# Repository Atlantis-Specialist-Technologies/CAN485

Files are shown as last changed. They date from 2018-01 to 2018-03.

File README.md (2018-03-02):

# CAN485
Repository for the Sparkfun AST-CAN485 Development Board

Sparkfun AST CAN485

[*Sparkfun AST CAN485 Development Board*](https://www.sparkfun.com/products/14483 "CAN485 on Sparkfun")

# Repository Contents
Repository for the CAN485 Board

* **/Libraries** - Libraries
* **/Examples** - Example code
* **/Documentation** - Documentation
* **/Firmware** - Arduino boards source
* **/Hardware** - Eagle design files

# Documentation
* **/Hookup Guide** - [Hookup guide](https://learn.sparkfun.com/tutorials/ast-can485-hookup-guide) for the CAN485. This contains everything needed to get up and running.

# Licensing
This product is open source.

Refer to LICENSE.md for license information

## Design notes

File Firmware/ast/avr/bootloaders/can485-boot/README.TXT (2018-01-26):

This directory contains the Optiboot small bootloader for AVR
microcontrollers, somewhat modified specifically for the Arduino
environment.

Modified by Atlantis Specialist Technologies
by James Blakey-Milner, 1 Aug 2017.
Added support for the AST CAN485 board
Note! AST modifications are in early development (alpha)
and are likely to change without notice.

Optiboot is more fully described here: http://github.com/Optiboot/optiboot
and is the work of Peter Knight (aka Cathedrow), building on work of Jason P
Kyle, Spiff, and Ladyada.  More recent maintenance and modifications are by
Bill Westfield (aka WestfW)

Arduino-specific issues are tracked as part of the Arduino project
at http://github.com/arduino/Arduino

Most of the information in this file is superceeded by the wiki content at
https://github.com/Optiboot/optiboot/wiki

It's till here "just in case."

------------------------------------------------------------

Building optiboot for Arduino.

Production builds of optiboot for Arduino are done on a Mac in "unix mode"
using CrossPack-AVR-20100115.  CrossPack tracks WINAVR (for windows), which
is just a package of avr-gcc and related utilities, so similar builds should
work on Windows or Linux systems.

One of the Arduino-specific changes is modifications to the makefile to
allow building optiboot using only the tools installed as part of the
Arduino environment, or the Arduino source development tree.  All three
build procedures should yield identical binaries (.hex files) (although
this may change if compiler versions drift apart between CrossPack and
the Arduino IDE.)

Building Optiboot in the Arduino IDE Install.

Work in the .../hardware/arduino/bootloaders/optiboot/ and use the
"omake <targets>" command, which just generates a command that uses
the arduino-included "make" utility with a command like:
    make OS=windows ENV=arduino <targets>
or  make OS=macosx ENV=arduino <targets>
On windows, this assumes you're using the windows command shell.  If
you're using a cygwin or mingw shell, or have one of those in your
path, the build will probably break due to slash vs backslash issues.
On a Mac, if you have the developer tools installed, you can use the
Apple-supplied version of make.
The makefile uses relative paths ("../../../tools/" and such) to find
the programs it needs, so you need to work in the existing optiboot
directory (or something created at the same "level") for it to work.

Building Optiboot in the Arduino Source Development Install.

In this case, there is no special shell script, and you're assumed to
have "make" installed somewhere in your path.
Build the Arduino source ("ant build") to unpack the tools into the
expected directory.
Work in Arduino/hardware/arduino/bootloaders/optiboot and use
    make OS=windows ENV=arduinodev <targets>
or  make OS=macosx ENV=arduinodev <targets>

Programming Chips Using the _isp Targets

The CPU targets have corresponding ISP targets that will actuall
program the bootloader into a chip. "atmega328_isp" for the atmega328,
for example.  These will set the fuses and lock bits as appropriate as
well as uploading the bootloader code.

ISP Targets in Version 5.0 and later:

The isp targets are now built using a separate "Makefile.isp" makefile,
which should make modification easier and more obvious.  This also fixes
the atmega8_isp target problem mentioned below.  The default
configuration assumes an ArduinoISP setup, but you will probably need to
update at least the serial port, since those are different for each
Arduino board and/or system/

ISP Targets in Version 4.6 and earlier:

The older makefiles default to using a USB programmer, but you can use a
serial programmer like ArduinoISP by changing the appropriate variables
when you invoke make:

   make ISPTOOL=stk500v1 ISPPORT=/dev/tty.usbserial-A20e1eAN  \
        ISPSPEED=-b19200 atmega328_isp

The "atmega8_isp" target does not currently work, because the mega8
doesn't have the "extended" fuse that the generic ISP target wants to
pass on to avrdude.  You'll need to run avrdude manually.

Standard Targets

I've reduced the pre-built and source-version-controlled targets
(.hex and .lst files included in the git repository) to just the
three basic 16MHz targets: atmega8, atmega16, atmega328.

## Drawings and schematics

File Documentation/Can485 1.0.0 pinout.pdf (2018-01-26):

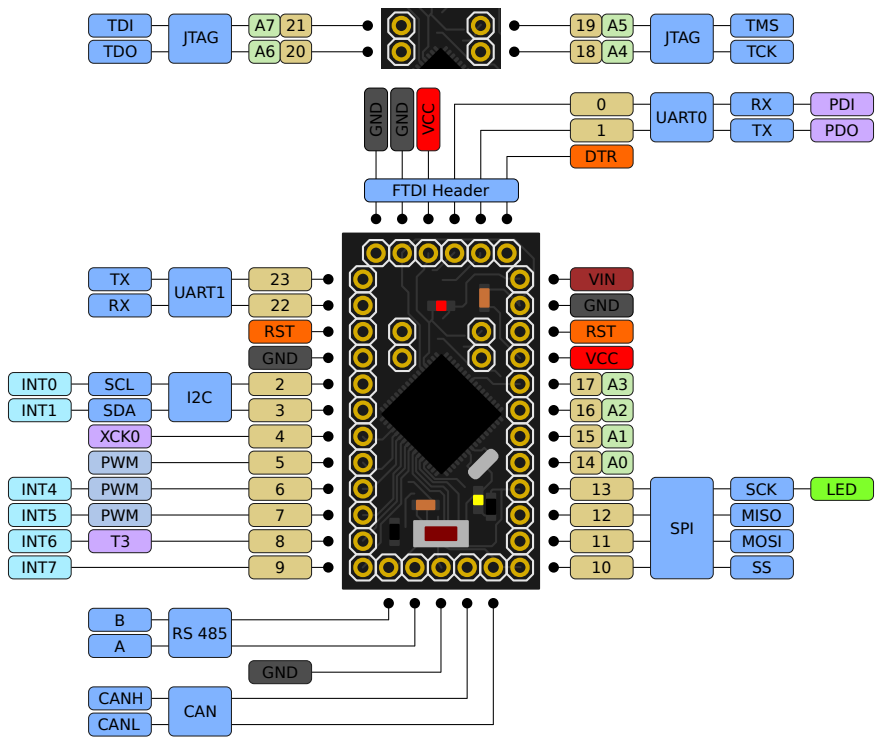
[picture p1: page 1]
VIN GND; MISO MOSI; SPI; SCK; VCC; RST; LED; UART0; DTR; GND; UART1; SCL SDA; CANH CANL; CAN; PDI PDO; XCK0 PWM PWM PWM; INT0 INT1; INT4 INT5 INT6 INT7; TCK; TDI; A7 21 A6 20 JTAG; FTDI Header

TMS JTAG TDO

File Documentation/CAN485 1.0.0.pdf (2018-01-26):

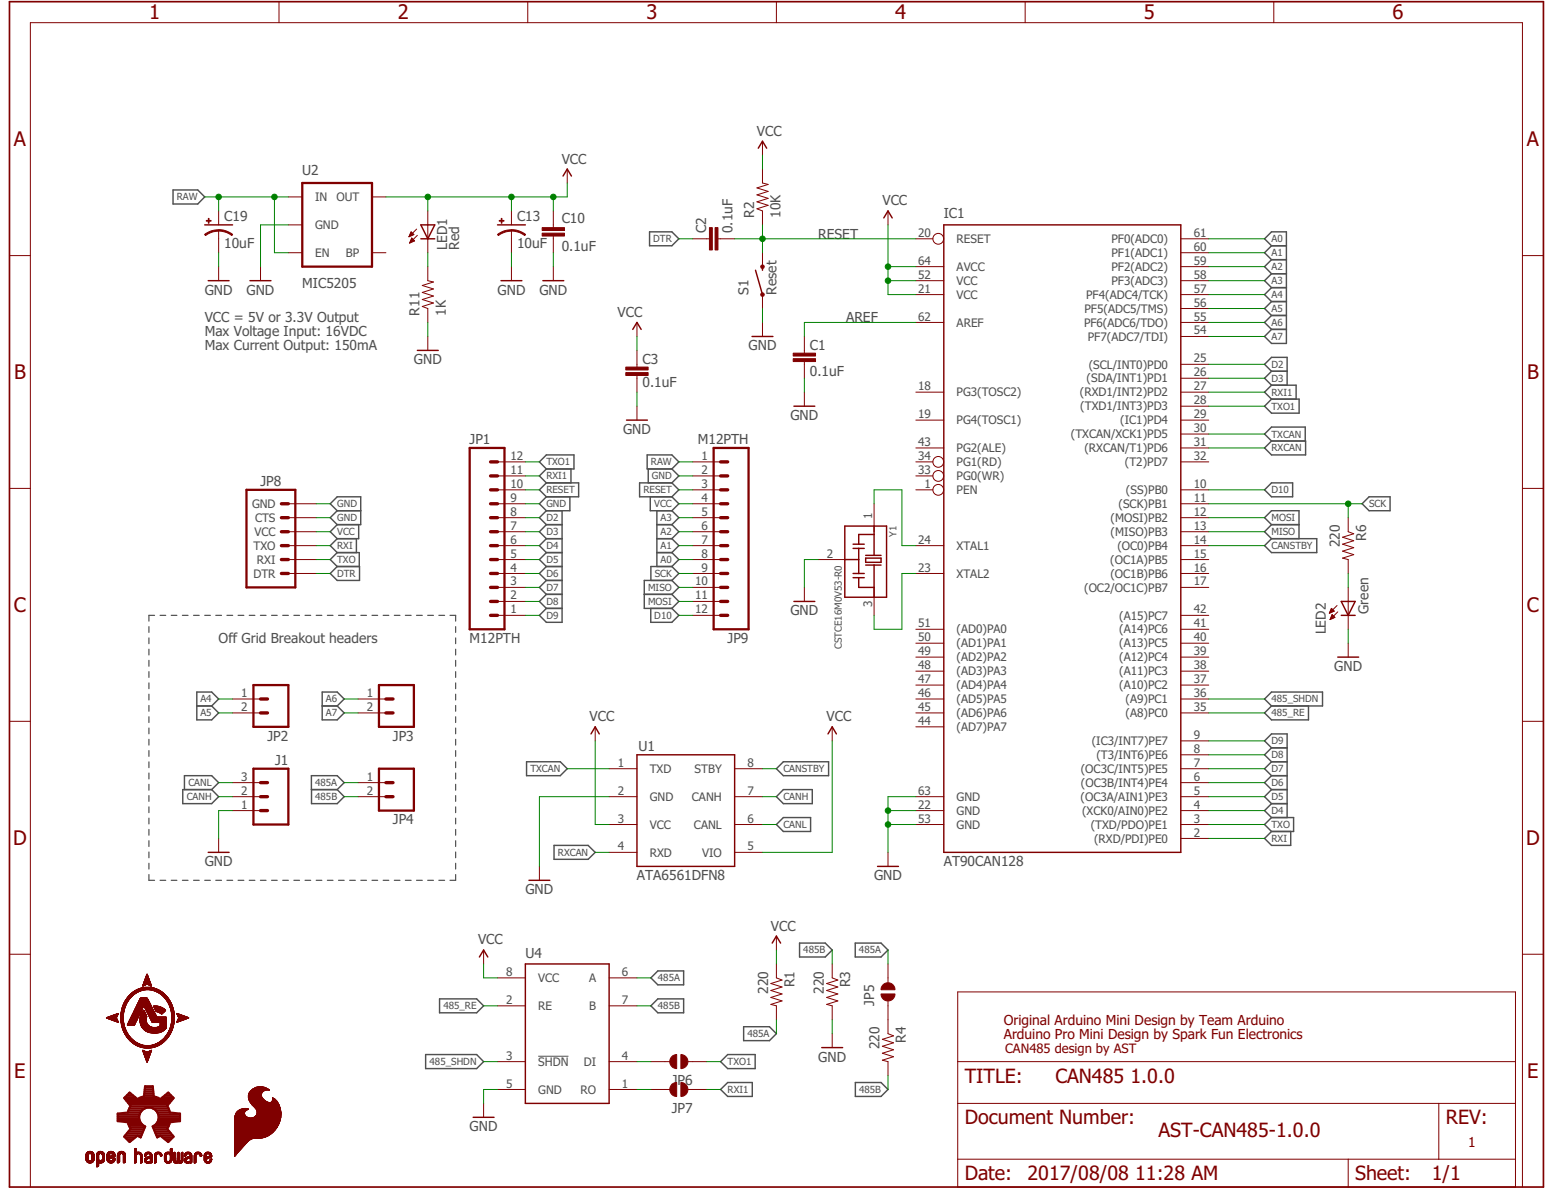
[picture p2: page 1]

VCC

Off Grid Breakout headers

Document Number: AST-CAN485-1.0.0 | REV: 1

Date: 2017/08/08 11:28 AM | Sheet: 1/1

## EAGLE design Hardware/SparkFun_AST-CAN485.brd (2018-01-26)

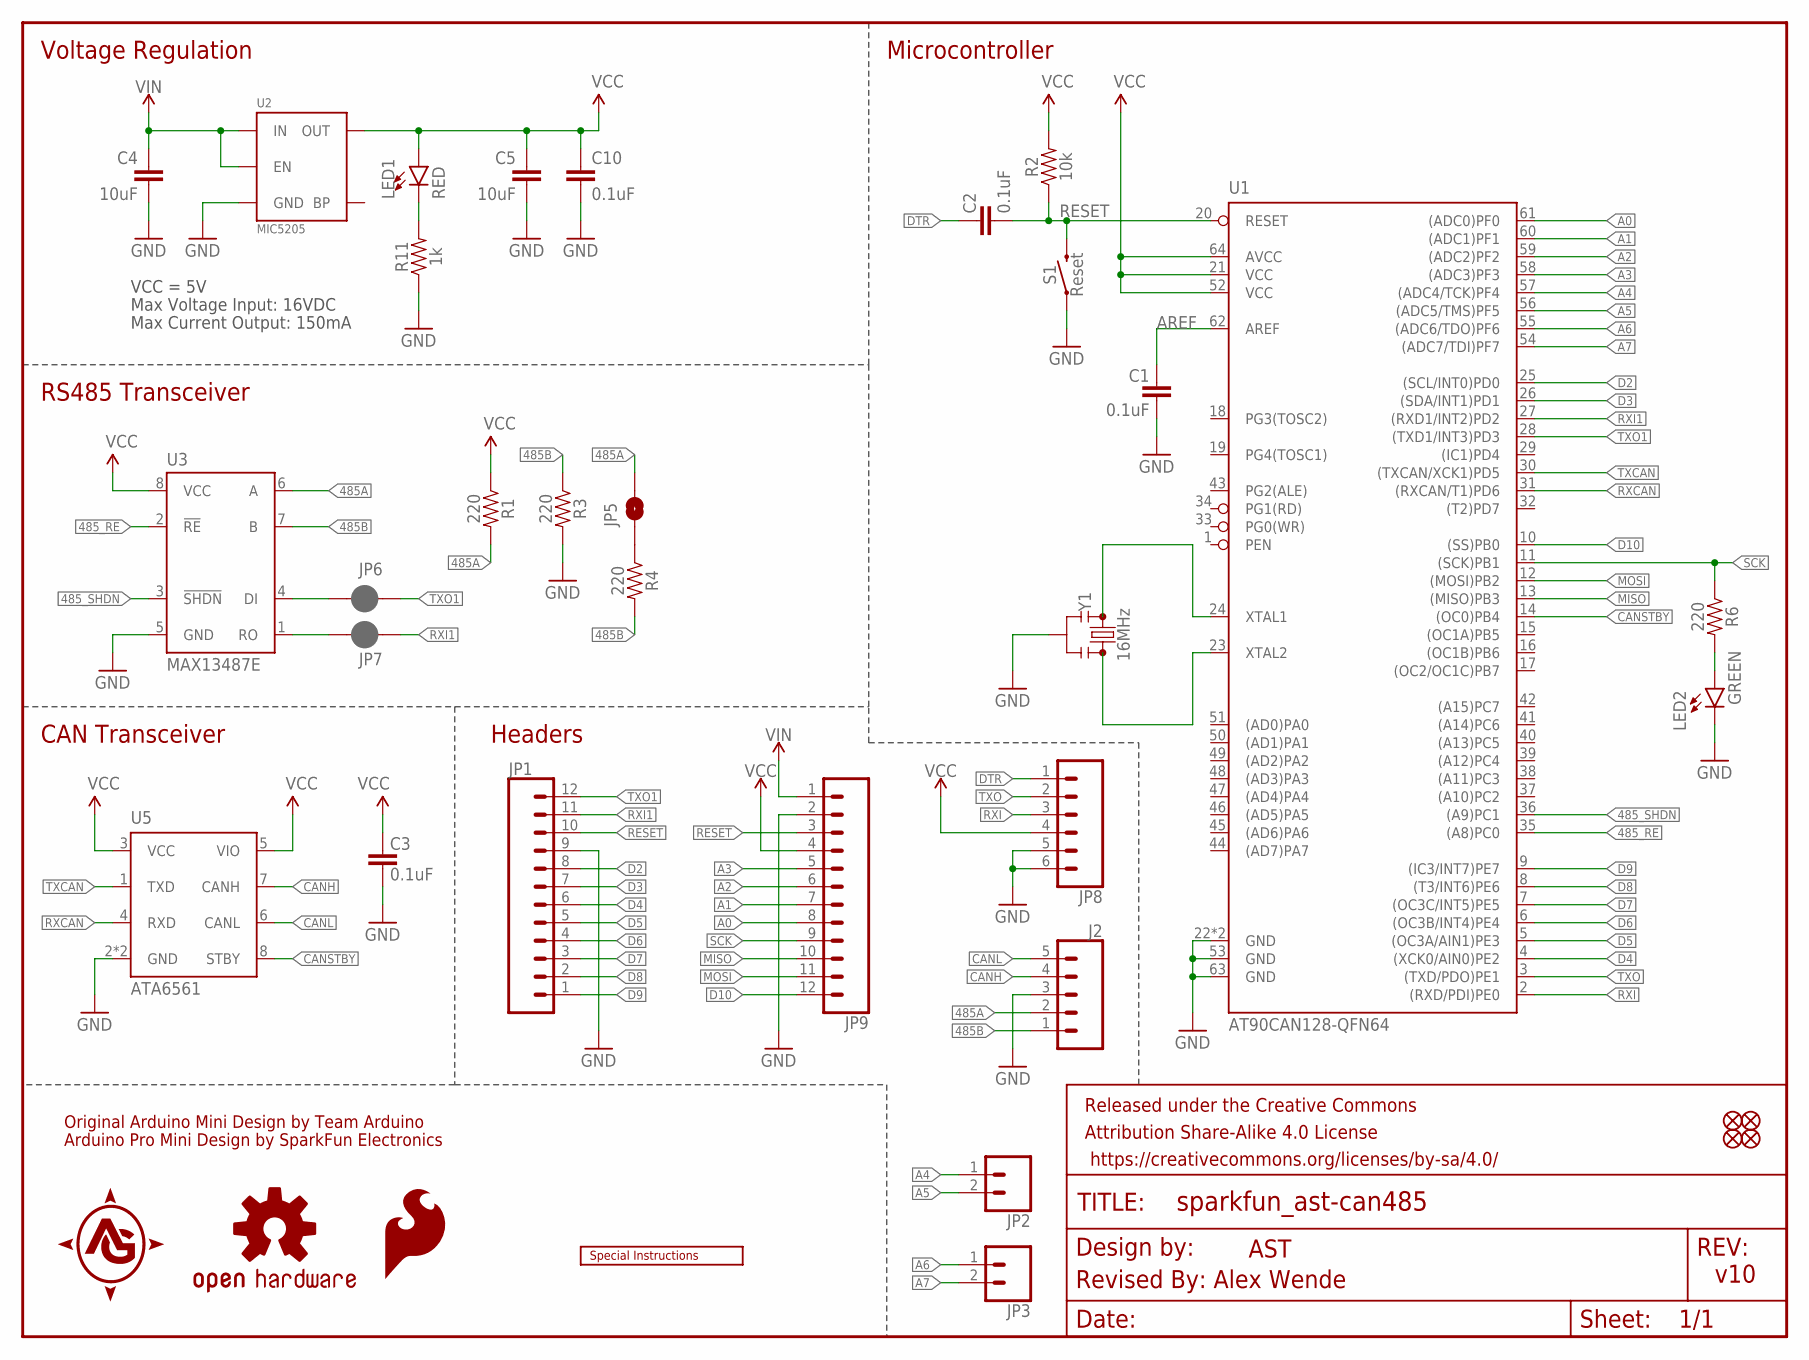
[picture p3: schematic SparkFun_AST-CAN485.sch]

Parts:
C1, C2, C3, C10: 0.1uF; 0402
C4, C5: 10uF; 1210
FD1, FD2, FD3, FD4: FIDUCIALUFIDUCIAL; FIDUCIAL-MICRO
FRAME1: FRAME-LETTER; CREATIVE_COMMONS
J2: CONN_05NO_SILK; 1X05_NO_SILK
JP1, JP9: CONN_12NO_SILK; 1X12_NO_SILK
JP2, JP3: CONN_021X02_NO_SILK; 1X02_NO_SILK
JP5: JUMPER-PAD-2-NO; PAD-JUMPER-2-NO_NO_SILK
JP6, JP7: JUMPER-SMT_2_NC_PASTE_NO-SILK; SMT-JUMPER_2_NC_PASTE_NO-SILK
JP8: CONN_06NO_SILK_NO_POP; 1X06_NO_SILK
LED1: RED; LED-0603
LED2: GREEN; LED-0603
LOGO1: OSHW-LOGOMINI; OSHW-LOGO-MINI
LOGO2: SFE_LOGO_FLAME0.05_INCH; SFE_LOGO_FLAME_.05
R1, R3, R4, R6: 220; 0603
R2: 10k; 0603
R11: 1k; 0603
S1: Reset; TACTILE_SWITCH_SMD_4.6X2.8MM
U1: AT90CAN128-QFN64; QFN-64
U2: MIC5205; SOT23-5
U3: MAX13487E; SO08
U5: ATA6561; DFN8
U$1: SPECIAL_INSTRUCTIONS-ORDERING; ORDERING_INSTRUCTIONS
Y1: 16MHz; RESONATOR-SMD-3.2X1.3(SLIM)

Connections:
485A: J2.2, JP5.2, R1.2, U3.6 (A)
485B: J2.1, R3.1, R4.2, U3.7 (B)
485_RE: U1.35 ((A8)PC0), U3.2 (!RE)
485_SHDN: U1.36 ((A9)PC1), U3.3 (!SHDN)
A0: JP9.8, U1.61 ((ADC0)PF0)
A1: JP9.7, U1.60 ((ADC1)PF1)
A2: JP9.6, U1.59 ((ADC2)PF2)
A3: JP9.5, U1.58 ((ADC3)PF3)
A4: JP2.1, U1.57 ((ADC4/TCK)PF4)
A5: JP2.2, U1.56 ((ADC5/TMS)PF5)
A6: JP3.1, U1.55 ((ADC6/TDO)PF6)
A7: JP3.2, U1.54 ((ADC7/TDI)PF7)
AREF: C1.2, U1.62 (AREF)
CANH: J2.4, U5.7 (CANH)
CANL: J2.5, U5.6 (CANL)
CANSTBY: U1.14 ((OC0)PB4), U5.8 (STBY)
D2: JP1.8, U1.25 ((SCL/INT0)PD0)
D3: JP1.7, U1.26 ((SDA/INT1)PD1)
D4: JP1.6, U1.4 ((XCK0/AIN0)PE2)
D5: JP1.5, U1.5 ((OC3A/AIN1)PE3)
D6: JP1.4, U1.6 ((OC3B/INT4)PE4)
D7: JP1.3, U1.7 ((OC3C/INT5)PE5)
D8: JP1.2, U1.8 ((T3/INT6)PE6)
D9: JP1.1, U1.9 ((IC3/INT7)PE7)
D10: JP9.12, U1.10 ((SS)PB0)
DTR: C2.2, JP8.1
GND: C1.1, C3.1, C4.2, C5.2, C10.2, J2.3, JP1.9, JP8.5, JP8.6, JP9.2, LED2.C, R3.2, R11.1, S1.1, S1.2 (1), U1.22 (GND), U1.53 (GND), U1.63 (GND), U1.65 (GND), U2.2 (GND), U3.5 (GND), U5.2 (GND), U5.9 (GND), Y1.2
MISO: JP9.10, U1.13 ((MISO)PB3)
MOSI: JP9.11, U1.12 ((MOSI)PB2)
unnamed: U1.23 (XTAL2), Y1.3
unnamed: U1.24 (XTAL1), Y1.1
unnamed: JP5.1, R4.1
unnamed: LED1.C, R11.2
unnamed: JP6.2, U3.4 (DI)
unnamed: JP7.2, U3.1 (RO)
unnamed: LED2.A, R6.2
RESET: C2.1, JP1.10, JP9.3, R2.1, S1.3 (2), S1.4 (2), U1.20 (RESET)
RXCAN: U1.31 ((RXCAN/T1)PD6), U5.4 (RXD)
RXI: JP8.3, U1.2 ((RXD/PDI)PE0)
RXI1: JP1.11, JP7.1, U1.27 ((RXD1/INT2)PD2)
SCK: JP9.9, R6.1, U1.11 ((SCK)PB1)
TXCAN: U1.30 ((TXCAN/XCK1)PD5), U5.1 (TXD)
TXO: JP8.2, U1.3 ((TXD/PDO)PE1)
TXO1: JP1.12, JP6.1, U1.28 ((TXD1/INT3)PD3)
VCC: C3.2, C5.1, C10.1, JP8.4, JP9.4, LED1.A, R1.1, R2.2, U1.21 (VCC), U1.52 (VCC), U1.64 (AVCC), U2.5 (OUT), U3.8 (VCC), U5.3 (VCC), U5.5 (VIO)
VIN: C4.1, JP9.1, U2.1 (IN), U2.3 (EN)

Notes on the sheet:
Original Arduino Mini Design by Team Arduino
Arduino Pro Mini Design by SparkFun Electronics
Max Voltage Input: 16VDC
Max Current Output: 150mA
VCC = 5V
Voltage Regulation
Microcontroller
RS485 Transceiver
CAN Transceiver
Headers
AST
Revised By: Alex Wende
v10

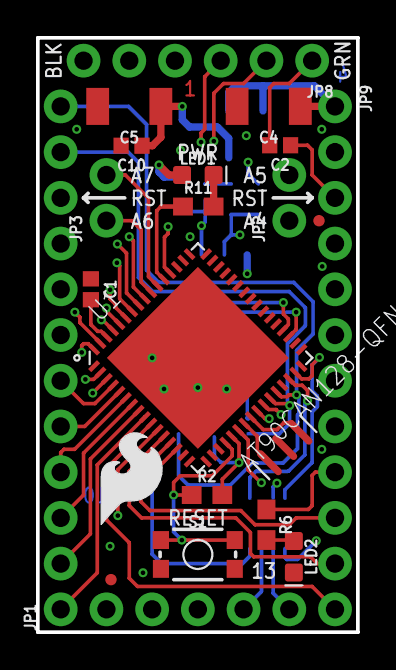
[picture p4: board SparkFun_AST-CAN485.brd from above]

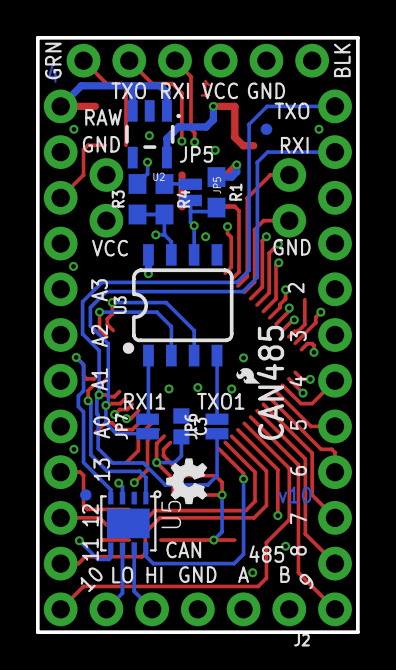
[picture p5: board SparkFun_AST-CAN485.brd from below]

Board: 4 copper layers, 17.8 x 33.0 mm, 38 parts (15 on the bottom side), 46 nets.

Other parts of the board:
LOGO3: SFE_LOGO_FLAME0.05_INCH; SFE_LOGO_FLAME_.2

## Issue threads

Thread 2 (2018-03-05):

execute two times the same statement for JTAG_Software_Disable ?

BlackBrix, 2018-03-05:
is it correct (or "wanted") to execute two times the same statement in
 `CAN485/Examples/JTAG_Software_Disable/JTAG_Software_Disable.ino` ?
https://github.com/Atlantis-Specialist-Technologies/CAN485/blob/5c797f7791b7f983c54843e09057ccb7788f478f/Examples/JTAG_Software_Disable/JTAG_Software_Disable.ino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
```
MCUCR = (1<<JTD);
MCUCR = (1<<JTD);
```

JamesBlakeyMilner, 2018-03-06:
It is necessary to write the JTD bit twice in order to disable the JTAG port. From the [Datasheet](https://github.com/Atlantis-Specialist-Technologies/CAN485/blob/master/Documentation/Datasheet%20AT90CANXX.pdf):

> 23.5.1 MCU Control Register – MCUCR
• Bits 7 – JTD: JTAG Interface Disable
When this bit is zero, the JTAG interface is enabled if the JTAGEN Fuse is programmed. If this
bit is one, the JTAG interface is disabled. In order to avoid unintentional disabling or enabling of
the JTAG interface, a timed sequence must be followed when changing this bit: The application
software must write this bit to the desired value twice within four cycles to change its value. Note
that this bit must not be altered when using the On-chip Debug system.

Also see [this](http://www.avrfreaks.net/forum/disabling-jtag-0) discussion

Whether this is the correct method is up for debate. A compiler may possibly interpret this differently and optimize out the second write or something (I am no compiler expert, this may or may not be an issue). In all test environments it has compiled correctly and worked. It may be "safer" to rewrite this in assembler to ensure the 4 cycle requirement is always met.

Will leave the issue open for now with the intention to investigate further.

Comments are welcome if anyone can advise on compiler interpretation.

BlackBrix, 2018-03-07:
aah, OK, I see ...

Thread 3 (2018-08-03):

ICSP header

obdevel, 2018-08-03:
There is no ICSP header on the board. Is it possible to upload sketches using a programmer or reinstall the bootloader ? If so, does it use the standard AVR SPI pins and which programmers are supported ? Thanks.

BlackBrix, 2018-08-03:
all your questions are answered in the "hookup-guide":
https://learn.sparkfun.com/tutorials/ast-can485-hookup-guide

obdevel, 2018-08-03:
Thank you. For posterity, the advice regarding Atmel Studio applies equally to the Arduino IDE. It works just fine for burning a bootloader and sketches using a USBasp programmer with the non-standard hookup. (Arduino 1.8.5, MacOS 10.13.5).

PS this is for my own-design board, not the Sparkfun CAN485 product ;)

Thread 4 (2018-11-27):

Sparkfun AST-CAN485 firmware corruption problem

omarachrafbrasil, 2018-11-27:
I have 3 Sparkfun AST-CAN485 board deployed in a solution to my customers. They had the firmwares corrupted after about 3 weeks of usage.

The firmware in the board interfaces a 3 axis joystick converting movements to Pelco-D packets in the 485 line. The board raw pin is connected to a 12.05 VDC Siemens power supply connected to a Inverter connected to a car battery on a running vehicle (car). I have a realy switch the turns on/off the 12 vdc line.
It was working for about 3 weeks and suddenly stopped. The AST-CAN85 firmware and its boot loader becomes corrupted.

Someone knows what can be happened?

Attached my diagram of the board and joystick.

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

Nom-it, 2020-03-11:
Hi Omarachrafbrasil,

I'm currently having sort of the same issue. Using a car battery to supply RAW voltage input, after a while, the firmware gets corrupted. (seems an EEprom corroption).
Did you eventually find the issue with the board/setup?

omarachrafbrasil, 2020-03-11:
Hi, after I set fuse bits to prevent brown out I don't the problem anymore.

Regards
Omar Achraf

Em qua, 11 de mar de 2020 10:52, Nom-it <notifications@github.com> escreveu:

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

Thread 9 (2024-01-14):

Folder structure capitalization typo prevents compiling sketches.

johnnaglak, 2024-01-14:
Hi!  I had some trouble getting sketches to compile.  I was getting an `/arduino/Arduino.h:258:10: fatal error: pins_arduino.h: No such file or directory #include "pins_arduino.h"` error when using the Board Manager and when manually installing the board definition.

After some trial and error, I identified that the path `/Firmware/ast/avr/varients/can485` does not match the capitalization of `Can485` in https://github.com/Atlantis-Specialist-Technologies/CAN485/blob/ff5446bde9ccd27d8d1a2495c56a0da5b0e55784/Firmware/ast/avr/boards.txt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

My solution was to manually edit and capitalize the folder name `/ast/avr/varients/Can485` on my system.  This should be a fairly simple fix in the repo.

Thanks, looking forward to using the board!

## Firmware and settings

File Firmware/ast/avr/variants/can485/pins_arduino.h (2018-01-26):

/*
  pins_arduino.h - Pin definition functions for Arduino
  Part of Arduino - http://www.arduino.cc/

  Copyright (c) 2007 David A. Mellis

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
  You should have received a copy of the GNU Lesser General
  Public License along with this library; if not, write to the
  Free Software Foundation, Inc., 59 Temple Place, Suite 330,
  Boston, MA  02111-1307  USA
*/

/*
  Modified by Atlantis Specialist Technologies
  by James Blakey-Milner, 1 Aug 2017.
  Added support for the AST CAN485 board
  Note! AST modifications are in early development (alpha)
  and are likely to change without notice.
*/

#ifndef Pins_Arduino_h
#define Pins_Arduino_h

#include <avr/pgmspace.h>

#define NUM_DIGITAL_PINS            24
#define NUM_ANALOG_INPUTS           8
#define analogInputToDigitalPin(p)  ((p < 8) ? (p) + 14 : -1)


#define digitalPinHasPWM(p)         (((p) == 5 || (p) == 6 || (p) == 7 )


#define PIN_SPI_SS    (10)
#define PIN_SPI_MOSI  (11)
#define PIN_SPI_MISO  (12)
#define PIN_SPI_SCK   (13)

static const uint8_t SS   = PIN_SPI_SS;
static const uint8_t MOSI = PIN_SPI_MOSI;
static const uint8_t MISO = PIN_SPI_MISO;
static const uint8_t SCK  = PIN_SPI_SCK;

#define PIN_WIRE_SDA        (3)
#define PIN_WIRE_SCL        (2)

static const uint8_t SDA = PIN_WIRE_SDA;
static const uint8_t SCL = PIN_WIRE_SCL;

#define LED_BUILTIN 13

#define PIN_A0   (14)
#define PIN_A1   (15)
#define PIN_A2   (16)
#define PIN_A3   (17)
#define PIN_A4   (18)
#define PIN_A5   (19)
#define PIN_A6   (20)
#define PIN_A7   (21)

static const uint8_t A0 = PIN_A0;
static const uint8_t A1 = PIN_A1;
static const uint8_t A2 = PIN_A2;
static const uint8_t A3 = PIN_A3;
static const uint8_t A4 = PIN_A4;
static const uint8_t A5 = PIN_A5;
static const uint8_t A6 = PIN_A6;
static const uint8_t A7 = PIN_A7;

// pin change interrupts not supported
#define digitalPinToPCICR(p)    ((uint8_t *)0)
#define digitalPinToPCICRbit(p) (NO_PIN_CHANGE_INTERRUPT)
#define digitalPinToPCMSK(p)    ((uint8_t *)0)
#define digitalPinToPCMSKbit(p) (NO_PIN_CHANGE_INTERRUPT_MASK)

//#define digitalPinToInterrupt(p)  ((p) == 2 ? 0 : ((p) == 3 ? 1 : NOT_AN_INTERRUPT))
#define digitalPinToInterrupt(p)  (((p) >= 6 && (p) <= 9) ? ((p) - 2) : (((p) == 2) ? 0 : (((p) == 3) ? 1 : NOT_AN_INTERRUPT)))         // AST done

#ifdef ARDUINO_MAIN

// On the Arduino board, digital pins are also used
// for the analog output (software PWM).  Analog input
// pins are a separate set.




// these arrays map port names (e.g. port B) to the
// appropriate addresses for various functions (e.g. reading
// and writing)

/*
 * See Arduino.h for use of these
 * ports start with PA = 1 (not 0)
 */
const uint16_t PROGMEM port_to_mode_PGM[] = {
	NOT_A_PORT,
	NOT_A_PORT,
	(uint16_t) &DDRB,
	(uint16_t) &DDRC,
	(uint16_t) &DDRD,
	(uint16_t) &DDRE,
	(uint16_t) &DDRF,
};

const uint16_t PROGMEM port_to_output_PGM[] = {
	NOT_A_PORT,
	NOT_A_PORT,
	(uint16_t) &PORTB,
	(uint16_t) &PORTC,
	(uint16_t) &PORTD,
	(uint16_t) &PORTE,
	(uint16_t) &PORTF,
};

const uint16_t PROGMEM port_to_input_PGM[] = {
	NOT_A_PORT,
	NOT_A_PORT,
	(uint16_t) &PINB,
	(uint16_t) &PINC,
	(uint16_t) &PIND,
	(uint16_t) &PINE,
	(uint16_t) &PINF,
};

const uint8_t PROGMEM digital_pin_to_port_PGM[] = {
	PE, /*  0 */
	PE, /*  1 */
	PD, /*  2 */
	PD, /*  3 */
	PE, /*  4 */
	PE, /*  5 */
	PE, /*  6 */
	PE, /*  7 */
	PE, /*  8 */
	PE, /*  9 */
	PB, /* 10 */
	PB, /* 11 */
	PB, /* 12 */
	PB, /* 13 */
	PF, /* 14 */
	PF, /* 15 */
	PF, /* 16 */
	PF, /* 17 */
	PF, /* 18 */
	PF, /* 19 */
	PF, /* 20 */
	PF, /* 21 */
	PC, /* 22 */
	PC, /* 23 */
};

const uint8_t PROGMEM digital_pin_to_bit_mask_PGM[] = {
	_BV(1), /*  0, PE1 				*/
	_BV(0), /*  1, PE0 				*/
	_BV(0), /*  2, PD0 				*/
	_BV(1), /*  3, PD1 				*/
	_BV(2), /*  4, PE2 				*/
	_BV(3), /*  5, PE3 				*/
	_BV(4), /*  6, PE4 				*/
	_BV(5), /*  7, PE5 				*/
	_BV(6), /*  8, PE6 				*/
	_BV(7), /*  9, PE7 				*/
	_BV(0), /* 10, PB0 				*/
	_BV(2), /* 11, PB2, MOSI 		*/
	_BV(3), /* 12, PB3, MISO 		*/
	_BV(1), /* 13, PB1, LED_BUILTIN */
	_BV(0), /* 14, PF0 				*/
	_BV(1), /* 15, PF1 				*/
	_BV(2), /* 16, PF2 				*/
	_BV(3), /* 17, PF3 				*/
	_BV(4), /* 18, PF4 				*/
	_BV(5), /* 19, PF5 				*/
	_BV(6), /* 20, PF6 				*/
	_BV(7), /* 21, PF7 				*/
	_BV(0), /* 22, PC0, RS485_RE	*/
	_BV(1), /* 23, PC1, RS485_SHDN	*/
};

const uint8_t PROGMEM digital_pin_to_timer_PGM[] = {
	NOT_ON_TIMER,
	NOT_ON_TIMER,
	NOT_ON_TIMER,
	NOT_ON_TIMER,
	NOT_ON_TIMER,
	TIMER3A, /*       5, PE3 */
	TIMER3B, /*       6, PE4 */
	TIMER3C, /*       7, PE5 */
	NOT_ON_TIMER,
	NOT_ON_TIMER,
	NOT_ON_TIMER,
	NOT_ON_TIMER,
	NOT_ON_TIMER,
	NOT_ON_TIMER,
	NOT_ON_TIMER,
	NOT_ON_TIMER,
	NOT_ON_TIMER,
	NOT_ON_TIMER,
	NOT_ON_TIMER,
	NOT_ON_TIMER,
	NOT_ON_TIMER,
	NOT_ON_TIMER,
	NOT_ON_TIMER,
	NOT_ON_TIMER,
};

#endif
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

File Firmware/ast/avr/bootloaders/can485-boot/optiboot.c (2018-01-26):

#define FUNC_READ 1
#define FUNC_WRITE 1
/**********************************************************/
/* Optiboot bootloader for Arduino                        */
/*                                                        */
/* http://optiboot.googlecode.com                         */
/*                                                        */
/* Arduino-maintained version : See README.TXT            */
/* http://code.google.com/p/arduino/                      */
/*  It is the intent that changes not relevant to the     */
/*  Arduino production envionment get moved from the      */
/*  optiboot project to the arduino project in "lumps."   */
/*                                                        */
/* Heavily optimised bootloader that is faster and        */
/* smaller than the Arduino standard bootloader           */
/*                                                        */
/* Enhancements:                                          */
/*   Fits in 512 bytes, saving 1.5K of code space         */
/*   Higher baud rate speeds up programming               */
/*   Written almost entirely in C                         */
/*   Customisable timeout with accurate timeconstant      */
/*   Optional virtual UART. No hardware UART required.    */
/*   Optional virtual boot partition for devices without. */
/*                                                        */
/* What you lose:                                         */
/*   Implements a skeleton STK500 protocol which is       */
/*     missing several features including EEPROM          */
/*     programming and non-page-aligned writes            */
/*   High baud rate breaks compatibility with standard    */
/*     Arduino flash settings                             */
/*                                                        */
/* Fully supported:                                       */
/*   ATmega168 based devices  (Diecimila etc)             */
/*   ATmega328P based devices (Duemilanove etc)           */
/*                                                        */
/* Beta test (believed working.)                          */
/*   ATmega8 based devices (Arduino legacy)               */
/*   ATmega328 non-picopower devices                      */
/*   ATmega644P based devices (Sanguino)                  */
/*   ATmega1284P based devices                            */
/*   ATmega1280 based devices (Arduino Mega)              */
/*                                                        */
/* Alpha test                                             */
/*   ATmega32                                             */
/*                                                        */
/* Work in progress:                                      */
/*   ATtiny84 based devices (Luminet)                     */
/*                                                        */
/* Does not support:                                      */
/*   USB based devices (eg. Teensy, Leonardo)             */
/*                                                        */
/* Assumptions:                                           */
/*   The code makes several assumptions that reduce the   */
/*   code size. They are all true after a hardware reset, */
/*   but may not be true if the bootloader is called by   */
/*   other means or on other hardware.                    */
/*     No interrupts can occur                            */
/*     UART and Timer 1 are set to their reset state      */
/*     SP points to RAMEND                                */
/*                                                        */
/* Code builds on code, libraries and optimisations from: */
/*   stk500boot.c          by Jason P. Kyle               */
/*   Arduino bootloader    http://arduino.cc              */
/*   Spiff's 1K bootloader http://spiffie.org/know/arduino_1k_bootloader/bootloader.shtml */
/*   avr-libc project      http://nongnu.org/avr-libc     */
/*   Adaboot               http://www.ladyada.net/library/arduino/bootloader.html */
/*   AVR305                Atmel Application Note         */
/*                                                        */

/* Copyright 2013-2015 by Bill Westfield.                 */
/* Copyright 2010 by Peter Knight.                        */
/*                                                        */
/* This program is free software; you can redistribute it */
/* and/or modify it under the terms of the GNU General    */
/* Public License as published by the Free Software       */
/* Foundation; either version 2 of the License, or        */
/* (at your option) any later version.                    */
/*                                                        */
/* This program is distributed in the hope that it will   */
/* be useful, but WITHOUT ANY WARRANTY; without even the  */
/* implied warranty of MERCHANTABILITY or FITNESS FOR A   */
/* PARTICULAR PURPOSE.  See the GNU General Public        */
/* License for more details.                              */
/*                                                        */
/* You should have received a copy of the GNU General     */
/* Public License along with this program; if not, write  */
/* to the Free Software Foundation, Inc.,                 */
/* 59 Temple Place, Suite 330, Boston, MA  02111-1307 USA */
/*                                                        */
/* Licence can be viewed at                               */
/* http://www.fsf.org/licenses/gpl.txt                    */
/*                                                        */
/**********************************************************/


/**********************************************************/
/*                                                        */
/* Optional defines:                                      */
/*                                                        */
/**********************************************************/
/*                                                        */
/* BIGBOOT:                                              */
/* Build a 1k bootloader, not 512 bytes. This turns on    */
/* extra functionality.                                   */
/*                                                        */
/* BAUD_RATE:                                             */
/* Set bootloader baud rate.                              */
/*                                                        */
/* SOFT_UART:                                             */
/* Use AVR305 soft-UART instead of hardware UART.         */
/*                                                        */
/* LED_START_FLASHES:                                     */
/* Number of LED flashes on bootup.                       */
/*                                                        */
/* LED_DATA_FLASH:                                        */
/* Flash LED when transferring data. For boards without   */
/* TX or RX LEDs, or for people who like blinky lights.   */
/*                                                        */
/* SUPPORT_EEPROM:                                        */
/* Support reading and writing from EEPROM. This is not   */
/* used by Arduino, so off by default.                    */
/*                                                        */
/* TIMEOUT_MS:                                            */
/* Bootloader timeout period, in milliseconds.            */
/* 500,1000,2000,4000,8000 supported.                     */
/*                                                        */
/* UART:                                                  */
/* UART number (0..n) for devices with more than          */
/* one hardware uart (644P, 1284P, etc)                   */
/*                                                        */
/**********************************************************/


/**********************************************************/
/* Version Numbers!                                       */
/*                                                        */
/* Arduino Optiboot now includes this Version number in   */
/* the source and object code.                            */
/*                                                        */
/* Version 3 was released as zip from the optiboot        */
/*  repository and was distributed with Arduino 0022.     */
/* Version 4 starts with the arduino repository commit    */
/*  that brought the arduino repository up-to-date with   */
/*  the optiboot source tree changes since v3.            */
/* Version 5 was created at the time of the new Makefile  */
/*  structure (Mar, 2013), even though no binaries changed*/
/* It would be good if versions implemented outside the   */
/*  official repository used an out-of-seqeunce version   */
/*  number (like 104.6 if based on based on 4.5) to       */
/*  prevent collisions.                                   */
/*                                                        */
/**********************************************************/

/**********************************************************/
/* Edit History:					  */
/*							  */
/* Aug 2014						  */
/* 6.2 WestfW: make size of length variables dependent    */
/*              on the SPM_PAGESIZE.  This saves space    */
/*              on the chips where it's most important.   */
/* 6.1 WestfW: Fix OPTIBOOT_CUSTOMVER (send it!)	  */
/*             Make no-wait mod less picky about	  */
/*               skipping the bootloader.		  */
/*             Remove some dead code			  */
/* Jun 2014						  */
/* 6.0 WestfW: Modularize memory read/write functions	  */
/*             Remove serial/flash overlap		  */
/*              (and all references to NRWWSTART/etc)	  */
/*             Correctly handle pagesize > 255bytes       */
/*             Add EEPROM support in BIGBOOT (1284)       */
/*             EEPROM write on small chips now causes err */
/*             Split Makefile into smaller pieces         */
/*             Add Wicked devices Wildfire		  */
/*	       Move UART=n conditionals into pin_defs.h   */
/*	       Remove LUDICOUS_SPEED option		  */
/*	       Replace inline assembler for .version      */
/*              and add OPTIBOOT_CUSTOMVER for user code  */
/*             Fix LED value for Bobuino (Makefile)       */
/*             Make all functions explicitly inline or    */
/*              noinline, so we fit when using gcc4.8     */
/*             Change optimization options for gcc4.8	  */
/*             Make ENV=arduino work in 1.5.x trees.	  */
/* May 2014                                               */
/* 5.0 WestfW: Add support for 1Mbps UART                 */
/* Mar 2013                                               */
/* 5.0 WestfW: Major Makefile restructuring.              */
/*             See Makefile and pin_defs.h                */
/*             (no binary changes)                        */
/*                                                        */
/* 4.6 WestfW/Pito: Add ATmega32 support                  */
/* 4.6 WestfW/radoni: Don't set LED_PIN as an output if   */
/*                    not used. (LED_START_FLASHES = 0)   */
/* Jan 2013						  */
/* 4.6 WestfW/dkinzer: use autoincrement lpm for read     */
/* 4.6 WestfW/dkinzer: pass reset cause to app in R2      */
/* Mar 2012                                               */
/* 4.5 WestfW: add infrastructure for non-zero UARTS.     */
/* 4.5 WestfW: fix SIGNATURE_2 for m644 (bad in avr-libc) */
/* Jan 2012:                                              */
/* 4.5 WestfW: fix NRWW value for m1284.                  */
/* 4.4 WestfW: use attribute OS_main instead of naked for */
/*             main().  This allows optimizations that we */
/*             count on, which are prohibited in naked    */
/*             functions due to PR42240.  (keeps us less  */
/*             than 512 bytes when compiler is gcc4.5     */
/*             (code from 4.3.2 remains the same.)        */
/* 4.4 WestfW and Maniacbug:  Add m1284 support.  This    */
/*             does not change the 328 binary, so the     */
/*             version number didn't change either. (?)   */
/* June 2011:                                             */
/* 4.4 WestfW: remove automatic soft_uart detect (didn't  */
/*             know what it was doing or why.)  Added a   */
/*             check of the calculated BRG value instead. */
/*             Version stays 4.4; existing binaries are   */
/*             not changed.                               */
/* 4.4 WestfW: add initialization of address to keep      */
/*             the compiler happy.  Change SC'ed targets. */
/*             Return the SW version via READ PARAM       */
/* 4.3 WestfW: catch framing errors in getch(), so that   */
/*             AVRISP works without HW kludges.           */
/*  http://code.google.com/p/arduino/issues/detail?id=368n*/
/* 4.2 WestfW: reduce code size, fix timeouts, change     */
/*             verifySpace to use WDT instead of appstart */
/* 4.1 WestfW: put version number in binary.		  */
/**********************************************************/

/**********************************************************/
/* Modified by Atlantis Specialist Technologies
/* by James Blakey-Milner, 1 Aug 2017.
/* Added support for the AST CAN485 board
/* Note! AST modifications are in early development (alpha)
/* and are likely to change without notice.
/**********************************************************/

#define OPTIBOOT_MAJVER 6
#define OPTIBOOT_MINVER 2

/*
 * OPTIBOOT_CUSTOMVER should be defined (by the makefile) for custom edits
 * of optiboot.  That way you don't wind up with very different code that
 * matches the version number of a "released" optiboot.
 */

#if !defined(OPTIBOOT_CUSTOMVER)
#define OPTIBOOT_CUSTOMVER 0
#endif

unsigned const int __attribute__((section(".version"))) 
optiboot_version = 256*(OPTIBOOT_MAJVER + OPTIBOOT_CUSTOMVER) + OPTIBOOT_MINVER;



#include <inttypes.h>
#include <avr/io.h>
#include <avr/pgmspace.h>
#include <avr/eeprom.h>
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
int main(void) {
  uint8_t ch;

  /*
   * Making these local and in registers prevents the need for initializing
   * them, and also saves space because code no longer stores to memory.
   * (initializing address keeps the compiler happy, but isn't really
   *  necessary, and uses 4 bytes of flash.)
   */
  register uint16_t address = 0;
  register pagelen_t  length;

  // After the zero init loop, this is the first code to run.
  //
  // This code makes the following assumptions:
  //  No interrupts will execute
  //  SP points to RAMEND
  //  r1 contains zero
  //
  // If not, uncomment the following instructions:
  // cli();
  asm volatile ("clr __zero_reg__");
  /* 
   * AST
   * Seems necessary to set SP manually
   */
#if defined(__AVR_ATmega8__) || defined (__AVR_ATmega32__) || defined (__AVR_ATmega16__)|| defined (__AVR_AT90CAN128__)
  SP=RAMEND;  // This is done by hardware reset
#endif

  /*
   * modified Adaboot no-wait mod.
   * Pass the reset reason to app.  Also, it appears that an Uno poweron
   * can leave multiple reset flags set; we only want the bootloader to
   * run on an 'external reset only' status
   */
#if !defined(__AVR_ATmega16__)
  ch = MCUSR;
  MCUSR = 0;
#else
  ch = MCUCSR;
  MCUCSR = 0;
#endif
  if (ch & (_BV(WDRF) | _BV(BORF) | _BV(PORF)))
      appStart(ch);

#if LED_START_FLASHES > 0
  // Set up Timer 1 for timeout counter
  TCCR1B = _BV(CS12) | _BV(CS10); // div 1024
#endif

#ifndef SOFT_UART
#if defined(__AVR_ATmega8__) || defined (__AVR_ATmega32__) || defined (__AVR_ATmega16__)
  UCSRA = _BV(U2X); //Double speed mode USART
  UCSRB = _BV(RXEN) | _BV(TXEN);  // enable Rx & Tx
  UCSRC = _BV(URSEL) | _BV(UCSZ1) | _BV(UCSZ0);  // config USART; 8N1
  UBRRL = (uint8_t)( (F_CPU + BAUD_RATE * 4L) / (BAUD_RATE * 8L) - 1 );
#else
  UART_SRA = _BV(U2X0); //Double speed mode USART0
  UART_SRB = _BV(RXEN0) | _BV(TXEN0);
  UART_SRC = _BV(UCSZ00) | _BV(UCSZ01);
  UART_SRL = (uint8_t)( (F_CPU + BAUD_RATE * 4L) / (BAUD_RATE * 8L) - 1 );
#endif
#endif

  // Set up watchdog to trigger after 1s
  watchdogConfig(WATCHDOG_1S);

#if (LED_START_FLASHES > 0) || defined(LED_DATA_FLASH)
  /* Set LED pin as output */
  LED_DDR |= _BV(LED);
#endif

#ifdef SOFT_UART
  /* Set TX pin as output */
  UART_DDR |= _BV(UART_TX_BIT);
#endif

#if LED_START_FLASHES > 0
  /* Flash onboard LED to signal entering of bootloader */
  flash_led(LED_START_FLASHES * 2);
#endif

  /* Forever loop: exits by causing WDT reset */
  for (;;) {
    /* get character from UART */
    ch = getch();

    if(ch == STK_GET_PARAMETER) {
      unsigned char which = getch();
      verifySpace();
      /*
       * Send optiboot version as "SW version"
       * Note that the references to memory are optimized away.
       */
      if (which == STK_SW_MINOR) {
	  putch(optiboot_version & 0xFF);
      } else if (which == STK_SW_MAJOR) {
	  putch(optiboot_version >> 8);
      } else {
	/*
	 * GET PARAMETER returns a generic 0x03 reply for
         * other parameters - enough to keep Avrdude happy
	 */
	putch(0x03);
      }
    }
    else if(ch == STK_SET_DEVICE) {
      // SET DEVICE is ignored
      getNch(20);
    }
    else if(ch == STK_SET_DEVICE_EXT) {
      // SET DEVICE EXT is ignored
      getNch(5);
    }
    else if(ch == STK_LOAD_ADDRESS) {
      // LOAD ADDRESS
      uint16_t newAddress;
      newAddress = getch();
      newAddress = (newAddress & 0xff) | (getch() << 8);
#ifdef RAMPZ
      // Transfer top bit to RAMPZ
      RAMPZ = (newAddress & 0x8000) ? 1 : 0;
#endif
      newAddress += newAddress; // Convert from word address to byte address
      address = newAddress;
      verifySpace();
    }
    else if(ch == STK_UNIVERSAL) {
      // UNIVERSAL command is ignored
      getNch(4);
      putch(0x00);
    }
    /* Write memory, length is big endian and is in bytes */
    else if(ch == STK_PROG_PAGE) {
      // PROGRAM PAGE - we support flash programming only, not EEPROM
      uint8_t desttype;
      uint8_t *bufPtr;
      pagelen_t savelength;

      GETLENGTH(length);
      savelength = length;
      desttype = getch();

      // read a page worth of contents
      bufPtr = buff;
      do *bufPtr++ = getch();
      while (--length);

      // Read command terminator, start reply
      verifySpace();

#ifdef VIRTUAL_BOOT_PARTITION
#if FLASHEND > 8192
/*
 * AVR with 4-byte ISR Vectors and "jmp"
 * WARNING: this works only up to 128KB flash!
 */
      if (address == 0) {
	// This is the reset vector page. We need to live-patch the
	// code so the bootloader runs first.
	//
	// Save jmp targets (for "Verify")
	rstVect0_sav = buff[rstVect0];
	rstVect1_sav = buff[rstVect1];
	saveVect0_sav = buff[saveVect0];
	saveVect1_sav = buff[saveVect1];

        // Move RESET jmp target to 'save' vector
        buff[saveVect0] = rstVect0_sav;
        buff[saveVect1] = rstVect1_sav;

        // Add jump to bootloader at RESET vector
        // WARNING: this works as long as 'main' is in first section
        buff[rstVect0] = ((uint16_t)main) & 0xFF;
        buff[rstVect1] = ((uint16_t)main) >> 8;
      }

#else
/*
 * AVR with 2-byte ISR Vectors and rjmp
 */
      if ((uint16_t)(void*)address == rstVect0) {
        // This is the reset vector page. We need to live-patch
        // the code so the bootloader runs first.
        //
        // Move RESET vector to 'save' vector
	// Save jmp targets (for "Verify")
	rstVect0_sav = buff[rstVect0];
	rstVect1_sav = buff[rstVect1];
	saveVect0_sav = buff[saveVect0];
	saveVect1_sav = buff[saveVect1];

	// Instruction is a relative jump (rjmp), so recalculate.
	uint16_t vect=(rstVect0_sav & 0xff) | ((rstVect1_sav & 0x0f)<<8); //calculate 12b displacement
	vect = (vect-save_vect_num) & 0x0fff; //substract 'save' interrupt position and wrap around 4096
        // Move RESET jmp target to 'save' vector
        buff[saveVect0] = vect & 0xff;
        buff[saveVect1] = (vect >> 8) | 0xc0; //
        // Add rjump to bootloader at RESET vector
        vect = ((uint16_t)main) &0x0fff; //WARNIG: this works as long as 'main' is in first section
        buff[0] = vect & 0xFF; // rjmp 0x1c00 instruction
	buff[1] = (vect >> 8) | 0xC0;
      }
#endif // FLASHEND
#endif // VBP

      writebuffer(desttype, buff, address, savelength);


    }
    /* Read memory block mode, length is big endian.  */
    else if(ch == STK_READ_PAGE) {
      uint8_t desttype;
      GETLENGTH(length);

      desttype = getch();

      verifySpace();

      read_mem(desttype, address, length);
    }

    /* Get device signature bytes  */
    else if(ch == STK_READ_SIGN) {
      // READ SIGN - return what Avrdude wants to hear
      verifySpace();
      putch(SIGNATURE_0);
      putch(SIGNATURE_1);
      putch(SIGNATURE_2);
    }
    else if (ch == STK_LEAVE_PROGMODE) { /* 'Q' */
      // Adaboot no-wait mod
      watchdogConfig(WATCHDOG_16MS);
      verifySpace();
    }
    else {
      // This covers the response to commands like STK_ENTER_PROGMODE
      verifySpace();
    }
    putch(STK_OK);
  }
}

void putch(char ch) {
#ifndef SOFT_UART
  while (!(UART_SRA & _BV(UDRE0)));
  UART_UDR = ch;
#else
  __asm__ __volatile__ (
    "   com %[ch]\n" // ones complement, carry set
    "   sec\n"
    "1: brcc 2f\n"
    "   cbi %[uartPort],%[uartBit]\n"
    "   rjmp 3f\n"
    "2: sbi %[uartPort],%[uartBit]\n"
    "   nop\n"
    "3: rcall uartDelay\n"
    "   rcall uartDelay\n"
    "   lsr %[ch]\n"
    "   dec %[bitcnt]\n"
    "   brne 1b\n"
    :
    :
      [bitcnt] "d" (10),
      [ch] "r" (ch),
      [uartPort] "I" (_SFR_IO_ADDR(UART_PORT)),
      [uartBit] "I" (UART_TX_BIT)
    :
      "r25"
  );
#endif
}

uint8_t getch(void) {
  uint8_t ch;

#ifdef LED_DATA_FLASH
#if defined(__AVR_ATmega8__) || defined (__AVR_ATmega32__) || defined (__AVR_ATmega16__)
  LED_PORT ^= _BV(LED);
#else
  LED_PIN |= _BV(LED);
#endif
#endif
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

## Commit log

2018-01-26 Arduino boards source
2018-01-26 Libraries, Documentation, Hardware
    [CAN485 1.0.0.brd, CAN485 1.0.0.sch]
2018-01-26 Update eagle files with Sparkfun revisions
    [CAN485 1.0.0.brd, CAN485 1.0.0.sch, SparkFun_AST-CAN485.brd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]
2018-03-06 Update JTAG disable example
    Added comment referring to an issue raised. Added blink code to test outputs
    [JTAG_Software_Disable.ino]

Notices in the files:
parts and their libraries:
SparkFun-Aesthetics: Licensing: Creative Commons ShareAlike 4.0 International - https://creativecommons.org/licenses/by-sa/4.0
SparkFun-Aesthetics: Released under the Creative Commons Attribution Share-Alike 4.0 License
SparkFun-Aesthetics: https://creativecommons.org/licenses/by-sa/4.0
